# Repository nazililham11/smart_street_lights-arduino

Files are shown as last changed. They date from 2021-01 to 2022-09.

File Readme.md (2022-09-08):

# Smart Street Lights

Alat ini diciptakan untuk memberikan kontribusi dan solusi pada pemerintah terkait permasalahan konsumsi listrik pada PJU yang relatif besar, apabila alat ini diterapkan, tentu akan menghemat konsumsi listrik yang dihabiskan oleh PJU. Dengan mengurangi konsumsi llistrik, secara tidak langsung juga mengurangi pembuangan gas emisi yang dihasilkan dari bahan fosil yang mana merupakan bahan bakar yang paling banyak digunakan sebagai pembangkit listrik PLN. Selain itu, penggunaan photovoltaik yang ramah lingkungan mendukung energi terbarukan yang selama ini digencarkan. 

## Komponen
 - Acrylic
 - Solar Panel 5v
 - Arduino
 - Sensor Ultrasonic
 - Mosfet IRF3205
 - LED 
 - Modul Stepup ke 5v
 - Modul Charger
 - Batterai 18650
 - Saklar
 - Kabel

## Sistem Kerja Alat
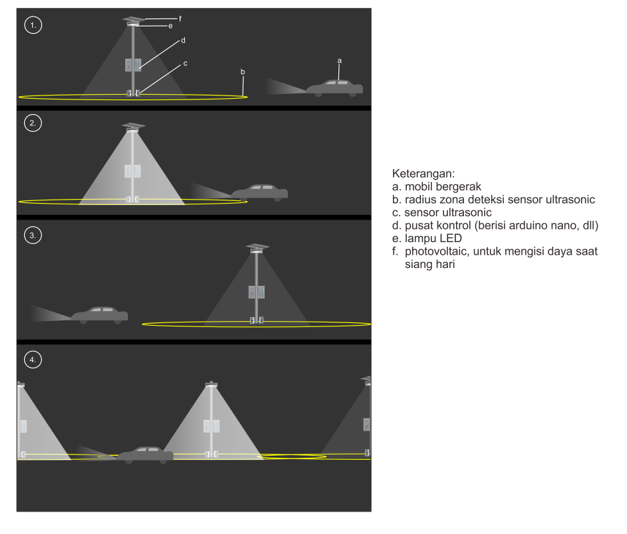
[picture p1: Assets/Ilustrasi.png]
Ilustrasi

1.	Keadaan lampu akan menyala redup ketika tidak ada objek datang di zona deteksi sensor ultrasonic
2.	Ketika mobil masuk dalam zona deteksi, lampu LED otomatis menyala terang, didukung dengan 2 buah  sensor ultrasonic untuk mendeteksi dua arah berlawanan zona deteksi dapat diatur jaraknya sesuai kebutuhan.
3.	Ketika mobil lepas dari zona deteksi lampu kembali menyala redup
4.	Pada penerapannya, zona deteksi diatur jaraknya sedemikian rupa agar tidak membahayakan pengendara yang melaju cepat (lampu harus menyala terang beberapa detik sebelum kendaraan lewat sehingga tidak mengganggu penglihatan pengendara)

## Konfigurasi Alat
**Posisi Jumper**
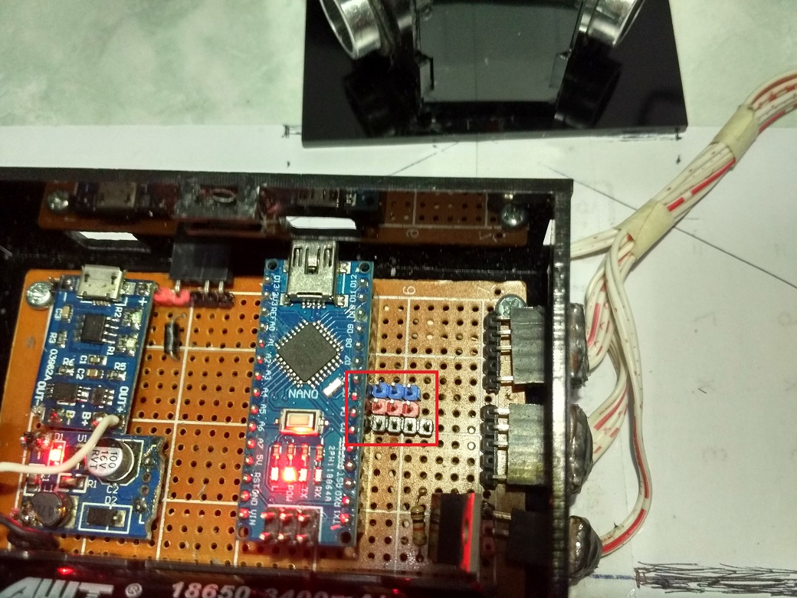
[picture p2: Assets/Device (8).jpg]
<br>

**Konfigurasi Jumper**
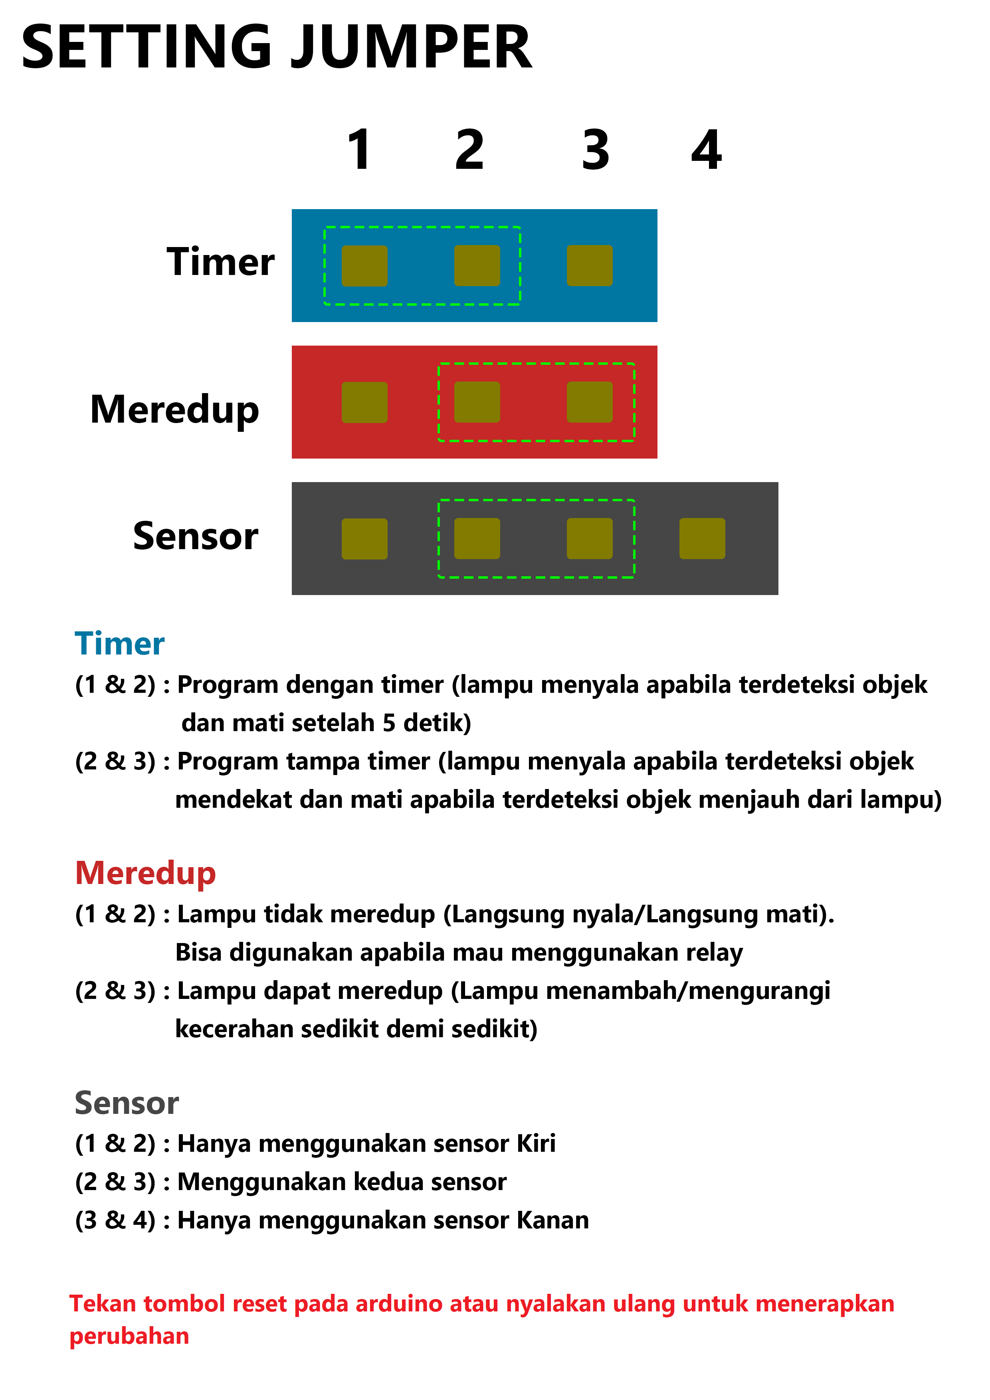
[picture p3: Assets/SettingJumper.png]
<br>

## Foto Alat
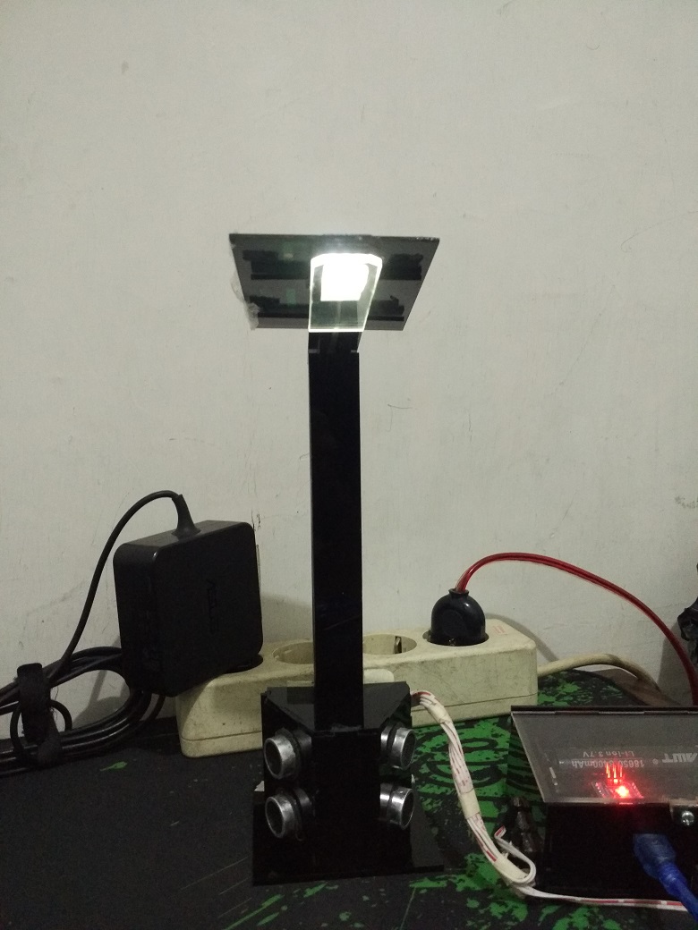
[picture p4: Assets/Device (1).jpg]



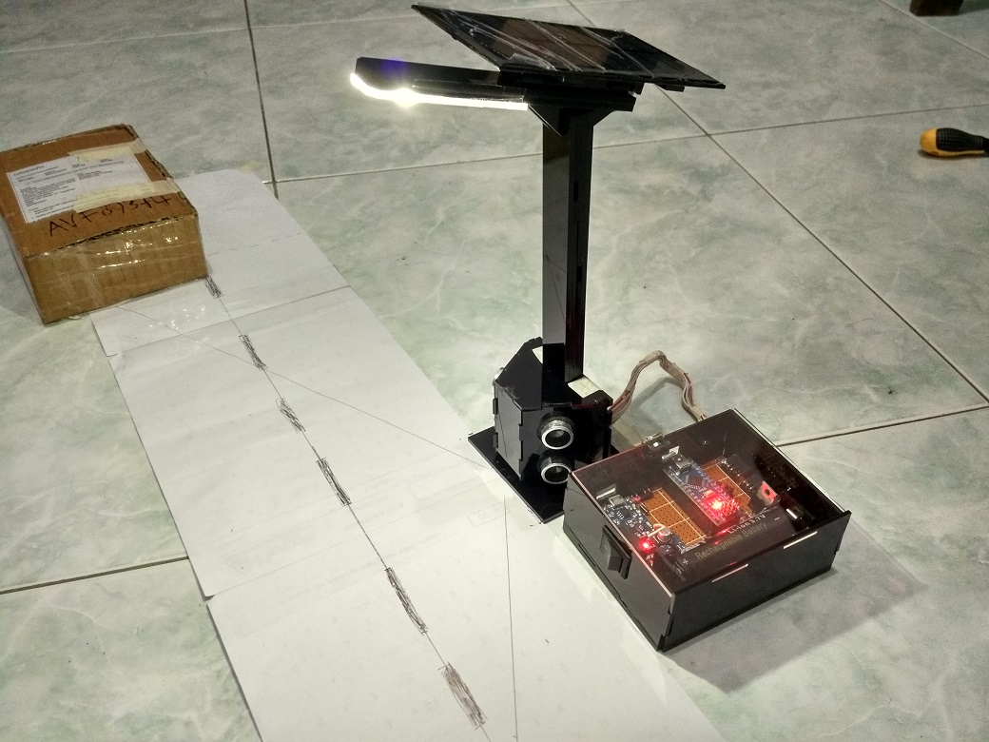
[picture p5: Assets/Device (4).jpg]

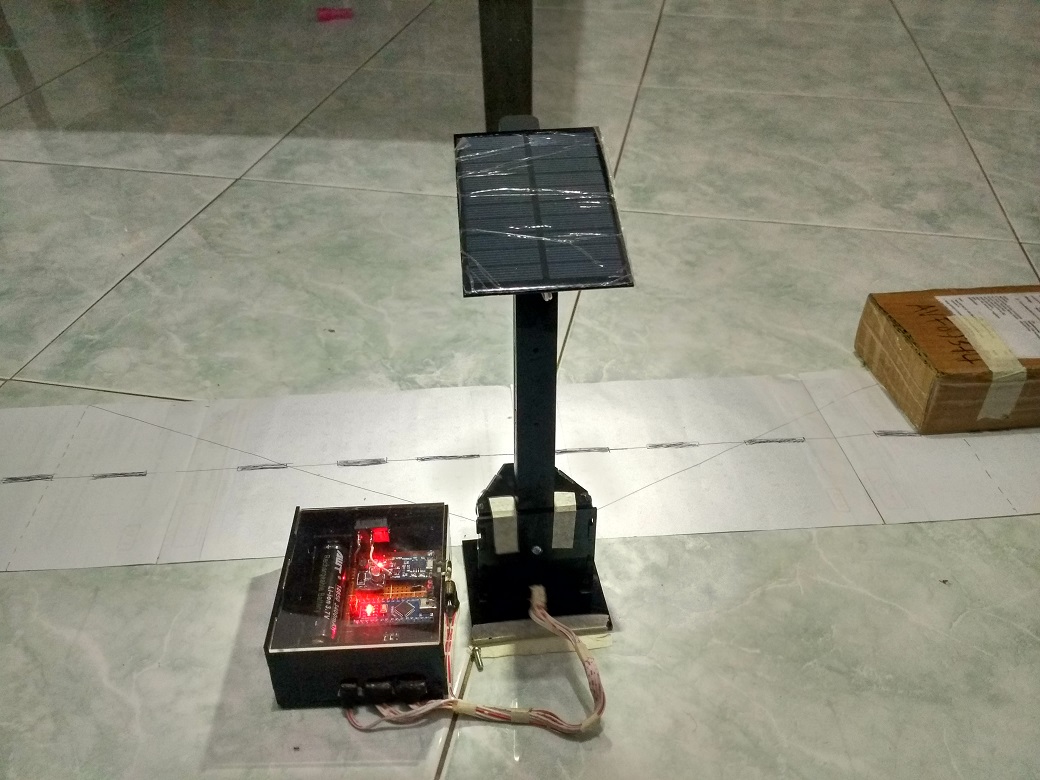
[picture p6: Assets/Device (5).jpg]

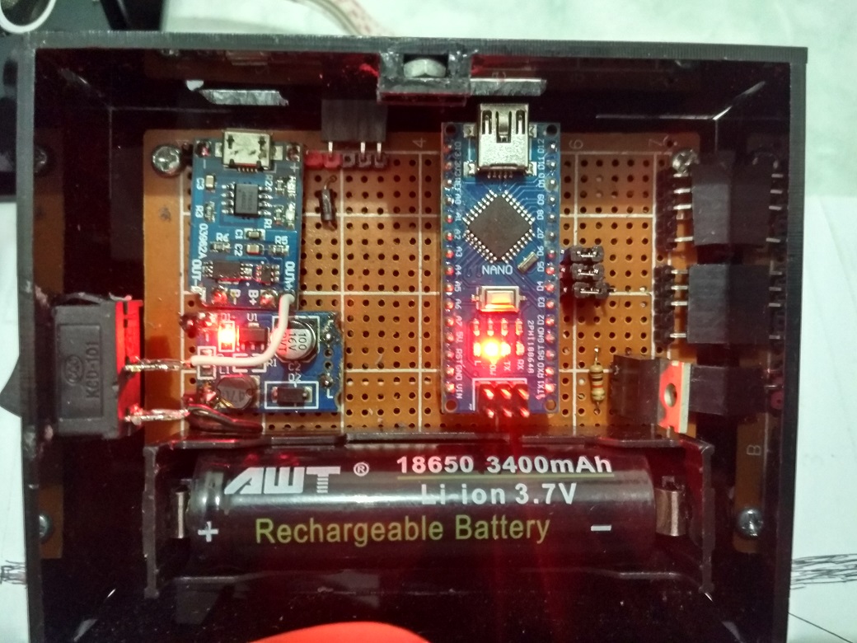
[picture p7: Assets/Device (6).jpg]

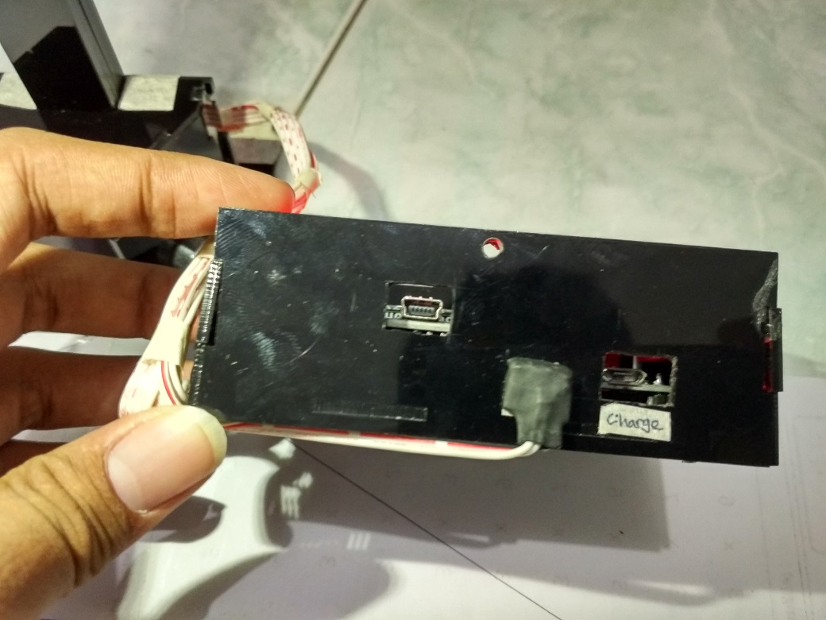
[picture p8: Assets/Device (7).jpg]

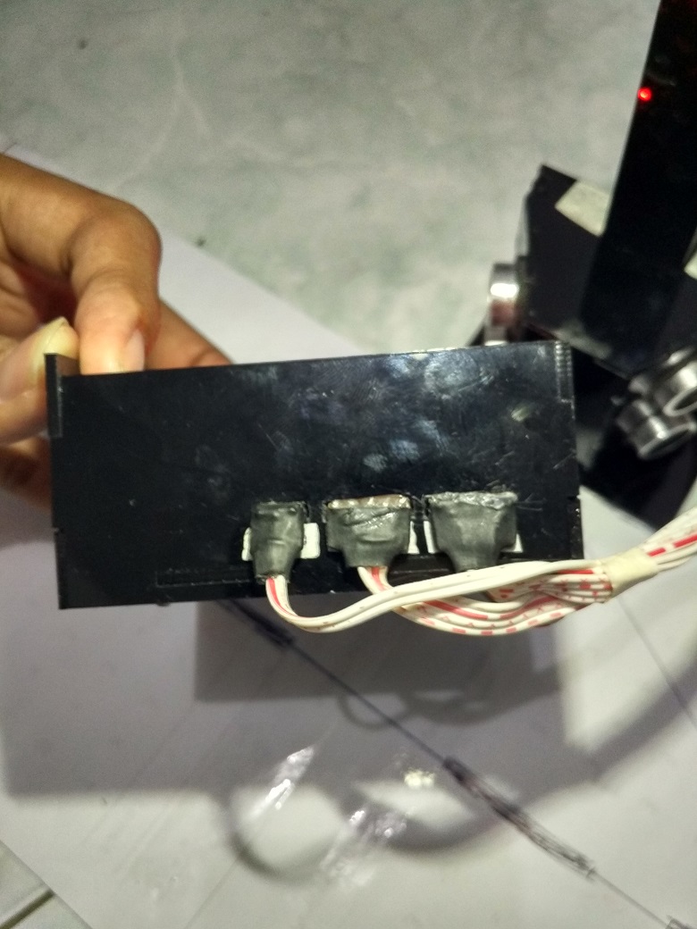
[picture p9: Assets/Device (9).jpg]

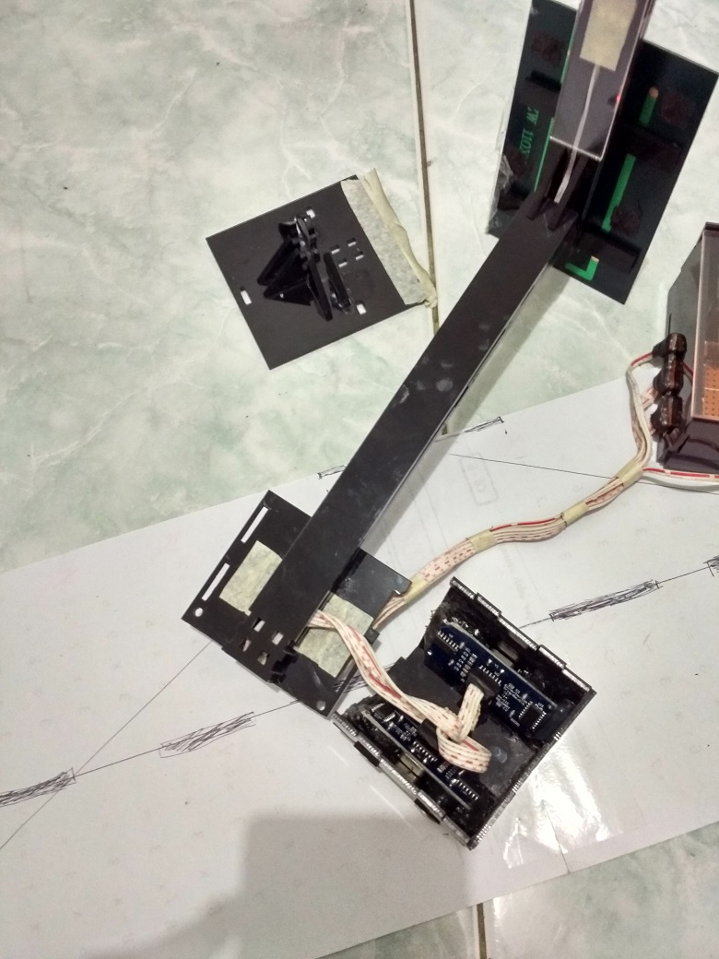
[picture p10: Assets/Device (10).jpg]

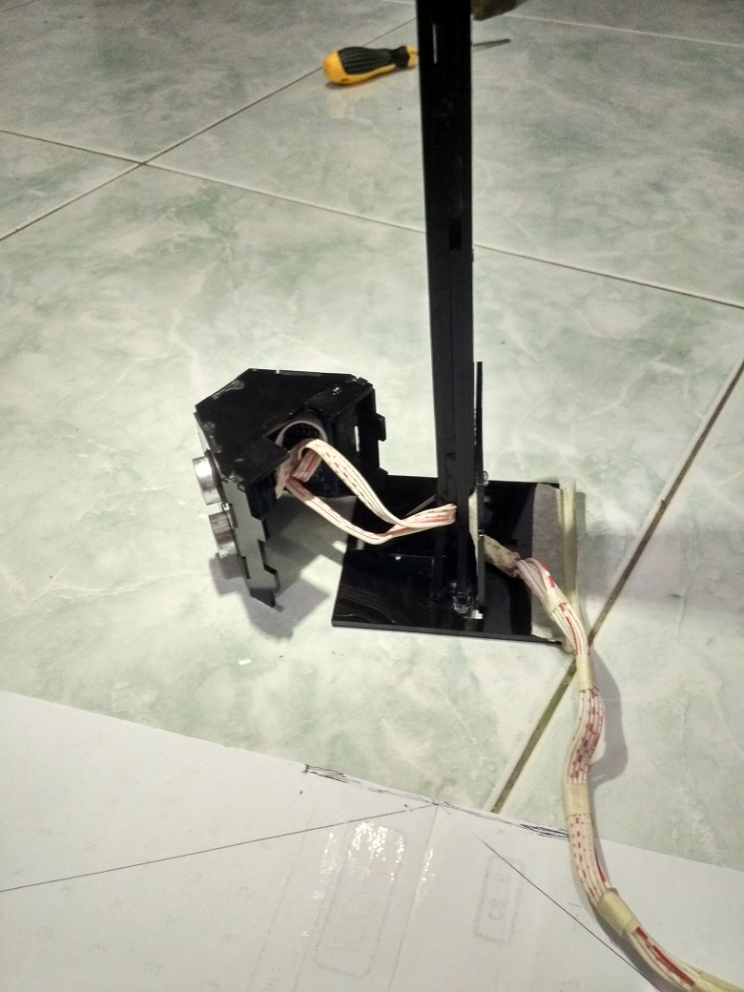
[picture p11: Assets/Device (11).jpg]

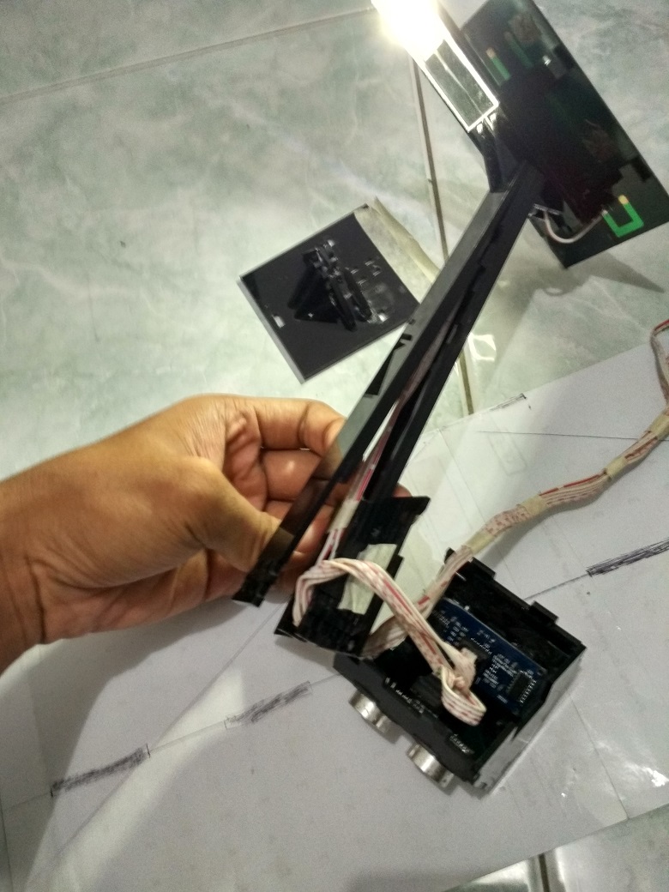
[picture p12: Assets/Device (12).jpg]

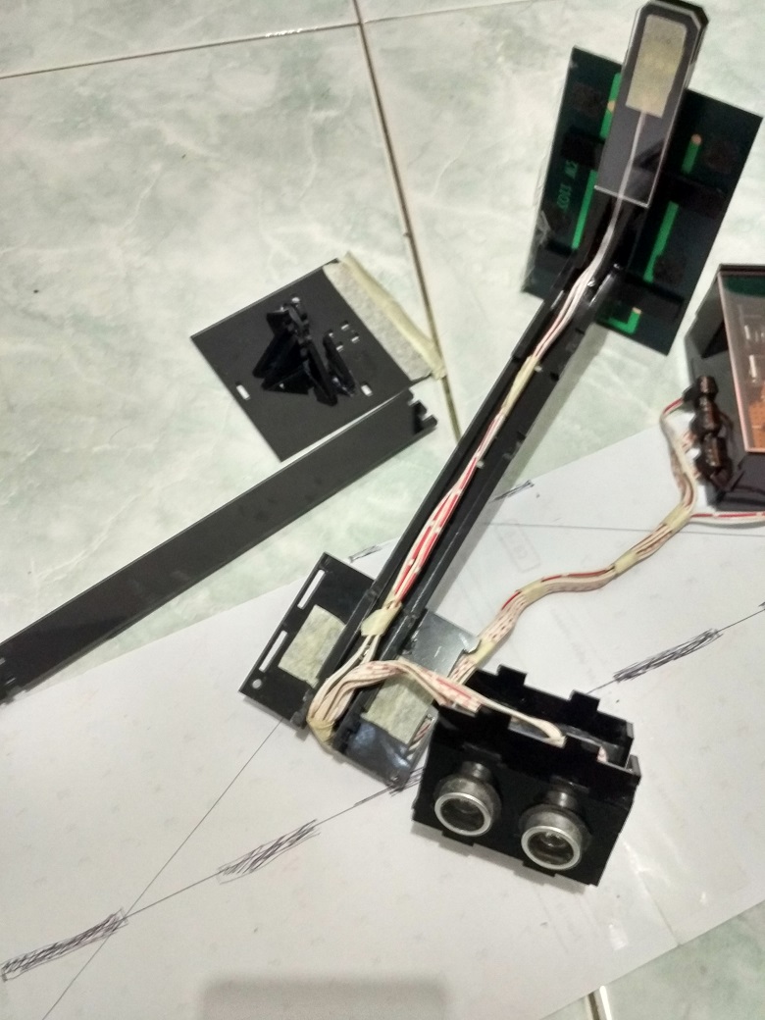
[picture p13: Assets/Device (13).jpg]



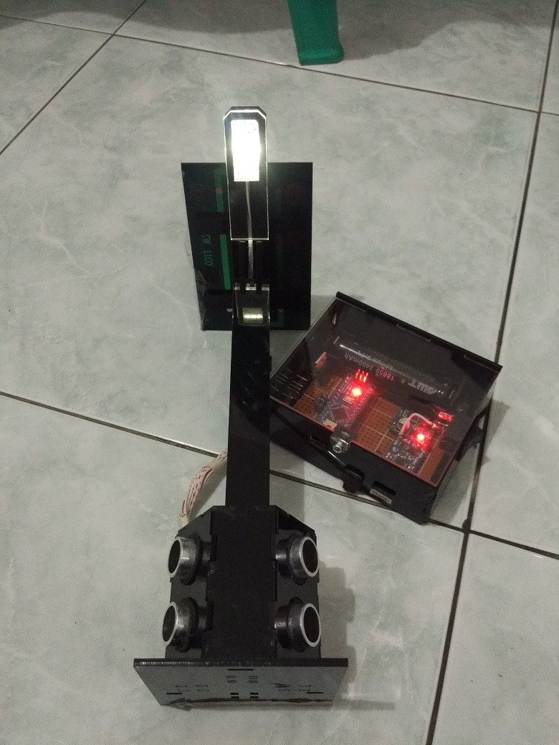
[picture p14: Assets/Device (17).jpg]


## Box Acrylic
Box Acrylic didesain dalam bentuk 3D ([Uncomplete 3D Design.skp](https://github.com/nazililham11/smart_street_lights-arduino/blob/a32a4c9f92976d29509b6a7dd917555c43372e27/Assets/Uncomplete%203D%20Design.skp)) untuk menentukan desain, sistem penguncian (untuk bongkar/pasang acrylic), tata letak, dan posisi dari hardware.

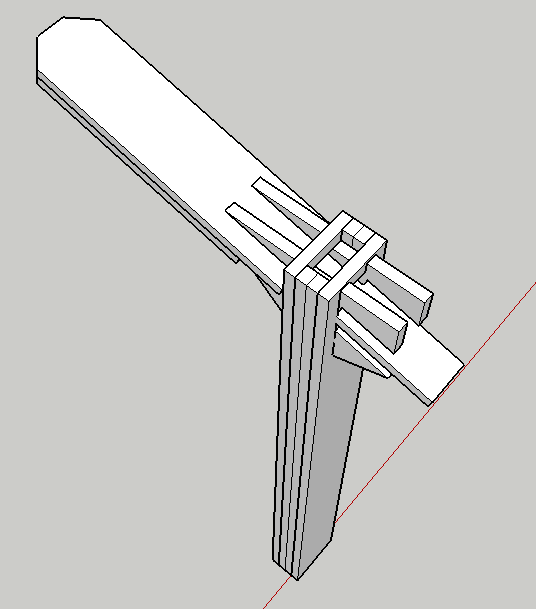
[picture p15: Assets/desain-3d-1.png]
Desain 3D

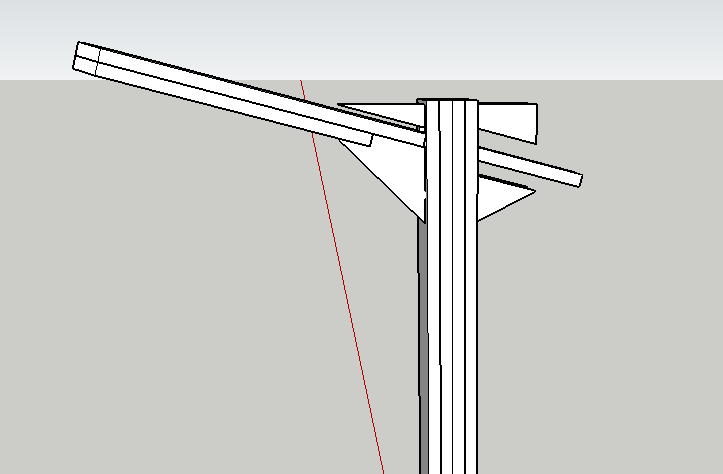
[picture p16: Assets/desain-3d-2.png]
Desain 3D

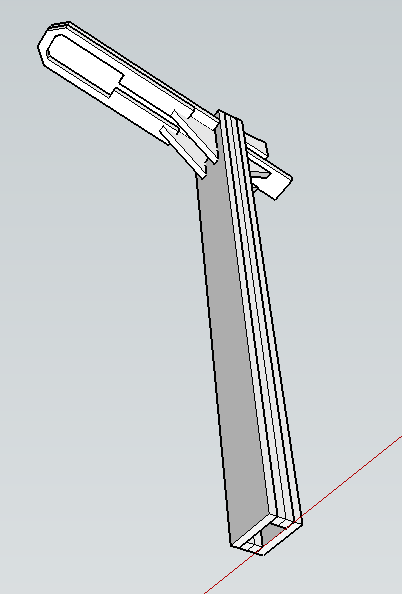
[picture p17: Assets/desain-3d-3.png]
Desain 3D


 Setelah desain 3D telah dibuat kemudian dibuat versi cutting acrylic ([acrylic.cdr](https://github.com/nazililham11/measurement_tool/raw/master/Assets/acrylic.cdr)) menggunakan aplikasi corel draw. Acrylic yang digunakan yaitu acrylic dengan tebal 2mm berwarna bening dan hitam.
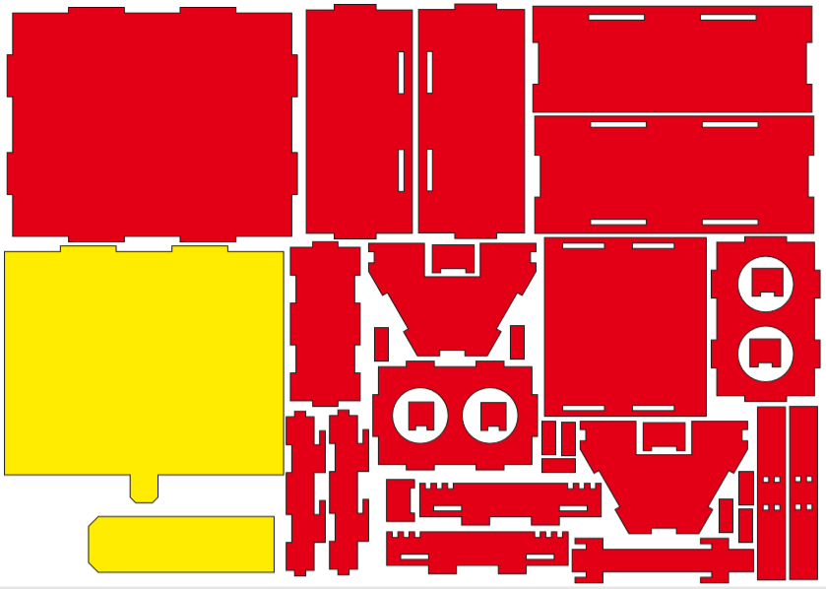
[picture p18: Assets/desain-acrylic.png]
Desain 3D
 
Kuning pada desain menunjukan acrylic bening dan merah menunjukan acrylic hitam.

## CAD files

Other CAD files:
Assets/Uncomplete 3D Design.skp

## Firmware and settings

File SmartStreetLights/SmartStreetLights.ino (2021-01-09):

/*
Jumpers Settings

 -----------
| 1 | 2 | 3 |                         : (1,2) Disable Stay Away, 
 -----------                            (2,3) En Stay Away [Default]
| 4 | 5 | 6 |                         : (4,5) Disable Dimmable, 
 ----------------                       (5,6) Enable Dimmable [Default]
| 7 | 8 | 9 | 10 |                    : (7,8) Enable Left, 
 ----------------                       (8,9) Enable Both [Default], 
                                        (9,10) Enable Right

*/




#include <NewPing.h>

#define DEBUG_MODE          true

//Pins
#define LAMP_PIN            3
#define EN_RIGHT_SENSOR     4
#define EN_DIMMABLE_PIN     5
#define EN_MODE_PIN         6
#define EN_LEFT_SENSOR      7

//Constant
#define NONE               -1
#define BOTH               -1
#define LEFT                0
#define RIGHT               1
#define INCREASE            0
#define DECREASE            1

// Sonar
#define SONAR_NUM           2
#define MAX_DISTANCE        100 //Cm
#define DISTANCE_THRESHOLD  30  //Cm

#if DEBUG_MODE

String SensDirecton[SONAR_NUM];

#endif


//Jumper Config
int8_t   EnabledSide;
bool     EnableDimmable;
bool     EnableStayAway;

// Lamp
const int16_t   MinBrightness = 10;
bool            IncreaseBrightness;
int16_t         LampBrightness;
int8_t          LampState = NONE;
const uint8_t   LampStep = 5;
const uint16_t  LampOnDelay = 5000;
unsigned long   LampOnMillis;
unsigned long   Millis;

// Sonar
const uint8_t   ErrorTolerance = 2;
bool            IsCarDetect[SONAR_NUM];
float           Distances[SONAR_NUM];
float           PrevDistances[SONAR_NUM];
uint16_t        GetClose[SONAR_NUM];
uint16_t        StayAway[SONAR_NUM];
uint8_t         ErrorCount[SONAR_NUM];

NewPing Sonar[SONAR_NUM] = {
    NewPing(12, 11, MAX_DISTANCE),  //Trigger, echo, and max distance. 
    NewPing(10, 9, MAX_DISTANCE), 
};


void setup() {
    #if DEBUG_MODE
    
    SensDirecton[LEFT] = String("Left");
    SensDirecton[RIGHT] = String("Right");
    Serial.begin(115200);
    #endif
    
    pinMode(LAMP_PIN, OUTPUT);
    pinMode(EN_MODE_PIN, INPUT_PULLUP);
    pinMode(EN_DIMMABLE_PIN, INPUT_PULLUP);
    pinMode(EN_LEFT_SENSOR, INPUT_PULLUP);
    pinMode(EN_RIGHT_SENSOR, INPUT_PULLUP);

    read_jumpers();

    #if DEBUG_MODE
    print_jumper();
    #endif
}

void loop() {

    //Read Handle
    read_distances();

    // Modes
    if (EnableStayAway) non_timer_mode();
    else                timer_mode();

    // Lamp Brightness Handler
    brightness_handle();

    // Lamp Handler
    if (EnableDimmable) dimmable();
    else                non_dimmable();

    // Debug
    #if DEBUG_MODE
    print_status();
    #endif
    
}


// Non Timer Mode
void non_timer_mode(){
    for (uint8_t i = 0; i < SONAR_NUM; i++){
        if (Distances[i] > 0 && Distances[i] < DISTANCE_THRESHOLD){
            if (PrevDistances[i] < 1){
                PrevDistances[i] = Distances[i];
            } else {
                if      (PrevDistances[i] >  Distances[i]) GetClose[i]++;
                else if (PrevDistances[i] <  Distances[i]) StayAway[i]++;
            }
        } else if (PrevDistances[i] > 0){                
            ErrorCount[i]++;
            if (ErrorCount[i] > ErrorTolerance){
                if      (GetClose[i] > StayAway[i]) LampState = INCREASE;
                else if (GetClose[i] < StayAway[i]) LampState = DECREASE;                    

                #if DEBUG_MODE
                if (LampState == INCREASE)      Serial.println("Car Get close from "+SensDirecton[i]);
                else if (LampState == DECREASE) Serial.println("Car Stay away from "+SensDirecton[i]);

                Serial.print("Away:" + String(StayAway[i]));
                Serial.print("\tClose:" + String(GetClose[i]));
                Serial.println();   
                #endif
                
                // reset distance status
                GetClose[i] = 0;
                StayAway[i] = 0;
                PrevDistances[i] = 0;
            }
        }
    }
}
// Timer mode
void timer_mode(){
    Millis = millis();

    if (Millis >= LampOnMillis + LampOnDelay){
        LampState = DECREASE;
        LampOnMillis = 0;
    }

    for (uint8_t i = 0; i < SONAR_NUM; i++){
        if (Distances[i] > 0 && Distances[i] < DISTANCE_THRESHOLD){
            LampState = INCREASE;
            LampOnMillis = Millis;

            #if DEBUG_MODE
            Serial.println("Trigger From "+SensDirecton[i]);            
            #endif
        }
    }
}

// Brightness Handle
void brightness_handle(){
    if (LampState != NONE){
        if (LampState == INCREASE) {
            LampBrightness += LampStep;
            LampBrightness = LampBrightness > 255 ? 255 : LampBrightness;
        } else if (LampState == DECREASE){
            LampBrightness -= LampStep;
            LampBrightness = LampBrightness < 0 ? 0 : LampBrightness;
        }
        if (LampBrightness <= 0 || LampBrightness >= 255){
            LampState = NONE;
        }
    }
}
// Dimmable Handle
void dimmable(){
    if (LampBrightness < MinBrightness) 
        analogWrite(LAMP_PIN, MinBrightness);
    else                           
        analogWrite(LAMP_PIN, LampBrightness);
}
void non_dimmable(){
    if (LampBrightness > 0)
        digitalWrite(LAMP_PIN, HIGH);
    else
        digitalWrite(LAMP_PIN, LOW);
}

// Read Distances
void read_distances(){
    if (EnabledSide == BOTH){
        for(uint8_t i = 0; i < SONAR_NUM; i++){
            unsigned long echoTime = Sonar[i].ping_median(3, MAX_DISTANCE);
            Distances[i] = NewPing::convert_cm(echoTime);
        }
    } else {
        unsigned long echoTime = Sonar[EnabledSide].ping_median(3, MAX_DISTANCE);
        Distances[EnabledSide] = NewPing::convert_cm(echoTime);
        Distances[EnabledSide == LEFT ? RIGHT : LEFT] = 0;
    }
}
// Read Jumpers
void read_jumpers(){
    EnabledSide   = !digitalRead(EN_LEFT_SENSOR) ? LEFT : 
                    !digitalRead(EN_RIGHT_SENSOR) ? RIGHT : BOTH;
    EnableDimmable = digitalRead(EN_DIMMABLE_PIN);
    EnableStayAway = digitalRead(EN_MODE_PIN);

    // Disable Stay Away if one of side was diabled
    if (EnabledSide != BOTH) EnableStayAway = false;
}


// Print Jumpers State
void print_jumper(){
    String enabledSide = EnabledSide == LEFT ? "LEFT" : 
                         EnabledSide == RIGHT ? "RIGHT" : "BOTH";
    Serial.print("Dimmable:"+String(EnableDimmable ? "Enabled" : "Disabled"));
    Serial.print("\tStayAway:"+String(EnableStayAway ? "Enabled" : "Disabled"));
    Serial.println("\tEn_Side:"+enabledSide);
}
// Print Current Status
void print_status(){
    Serial.print("State:"+String(LampState));
    Serial.print("\tBrightness:"+String(LampBrightness));
    Serial.print("\tleft:"+String(Distances[LEFT]));
    Serial.println("\tright:"+String(Distances[RIGHT]));
}
